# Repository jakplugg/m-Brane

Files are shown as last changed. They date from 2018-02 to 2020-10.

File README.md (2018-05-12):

# m-Brane
6hp eurorack module, compact verion of Mutable Instruments Yarns.

Google sheet BOM:
https://docs.google.com/spreadsheets/d/1MqaRt3kgtec8WGIdC7prpy5DM8mcHv3j_mBwdBO56kk/edit?usp=sharing

CC-BY-SA-3.0 (todo:add license file)

re the MIDI jacks, you can use kobiconn stereo jacks (pc mount, not solder tab) instead of the thonk ones, but you should pull them up to the panel with the nut before soldering them, because they are a little shorter than the thonk ones.

Note: Early versions of the board have the gate outs reversed, (but not the LEDs) there is an alternative firmware in the "reverse_gates_firmware" folder

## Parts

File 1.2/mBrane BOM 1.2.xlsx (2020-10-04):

 | RefDes | Value | Name | Mouser | Notes
4 | C14, C16, C21, C22 | 18p | C-USC0603 | 81-GRM185C1H180JA01J
13 | C2, C5, C6, C8, C9, C11, C13, C18, C19, C20, C23, C24, C27 | 100n | C-USC0603 | 963-EMK107BJ104KAHT
1 | C17 | 220n | C-USC0603 | 81-GRM188R71C224KA1J
2 | C25, C26 | 1u | C-USC0603 | 81-GRM188R61E105KA2J
1 | C15 | 3.3u | C-USC0603 | 81-GRM188R61A335KE5D
2 | C3, C12 | 10u | CPOL-USA | 647-UWP1A100MCL
2 | C1, C4 | 22u | CPOL-USC | 667-EEE-FK1E220R
2 | R39, R40 | 51 | R-US_R0603 | 603-RC0603FR-0751RL (https://www.mouser.com/ProductDetail/Yageo/RC0603FR-0751RL?qs=sGAEpiMZZMu61qfTUdNhG5eFuApKbqVdiaQZYTuEmh8%3d)
18 | R2, R3, R4, R5, R6, R7, R8, R10, R11, R12, R13, R14, R15, R16, R33, R36, R41, R42 | 100 | R-US_R0603 | 603-RC0603FR-07100RL
1 | R75 | 220 | R-US_R0603 | 603-RC0603FR-07220RL
10 | R1, R9, R24, R25, R30, R31, R32, R34, R38, R43 | 1.0k | R-US_R0603 | RC0603FR-071KL
2 | R17, R37 | 10k | R-US_R0603 | 603-RC0603FR-0710KL
6 | R18, R19, R20, R21, R22, R23 | 47k | R-US_R0603 | 603-RC0603FR-0747KL
4 | R26, R27, R28, R29 | 240k | R-US_R0603 | RC0603FR-07240KL
1 | D20 | MB1S | MB1S | 512-MB1S
1 | D1, D2 | BAT54S | DIODE
1 | IC1 | LM1117-3.3 | REG1117 | 926-LM1117MPX3.3NOPB
2 | IC2, IC3 | 74HC595D | 74HC595D | 595-CD74HC595M
1 | IC4 | DAC8564 | DAC8564 | 595-DAC8564IDPW
1 | IC5 | REF02D | REF02D | 595-REF02AU
1 | IC6 | OPA4171 | TL074D | 595-OPA4171AIDR
4 | IC7, IC8, IC10, IC11 | 74AHCT1G125DBV | 74AHCT1G125DBV | 595-SNAHCT1G125DBVR
1 | IC9 | MCP1703CB | MCP1703CB | 579-MCP1703T-5002ECB
1 | UC1 | STM32F103CBT6 | STM32F103CB | 511-STM32F103CBT6
1 | U10 | 8 mhz resonator | smd-crystal | CSTCE8M00GH5C99-R0
2 | Q1, Q2 | MMBT3904 | MMBT3904LT1-NPN-SOT23-BEC | 863-MMBT3904LT1G
1 | OK1 | 6N137SMT | 6N137SMT | 512-HCPL0600
26 | Unique
86 | Total

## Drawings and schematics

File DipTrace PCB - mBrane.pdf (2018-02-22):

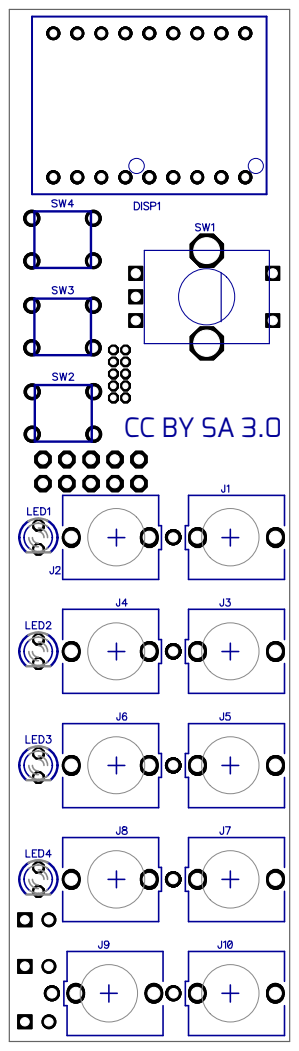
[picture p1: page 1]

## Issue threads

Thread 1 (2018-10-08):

Midi In doesn't work

gboxentertainment, 2018-10-08:
I built a Midi (male) to 3.5mm TRS adapter, but have not been able to get it to work with the m-Brane. I have tested this cable on other hardware and it sends midi fine.

I switch Tempo to Ext and Channel to All.

I have tried switching pins 4 and 5 on the midi pinout connections but it doesn't make a difference. I have found that connecting Tip to pin 5 and Ring to pin 4 makes the midi cable work as a trigger directly into any trigger inputs on any of my modules. But no matter which way I switch it, I still can't get Midi working on the m-Brane. I have Sleeve connected to pin 2 on the midi socket.

I suspect that it may be the HCPL0600, which you have on your BOM to replace the 6N137 from the original Yarns. It has slightly different specs but the internal circuits are the same.

Closed 2020-09-15.

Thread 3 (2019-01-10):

possible to post sysex for reversed gates firmware?

seanrieger, 2019-01-10:
So I am one of the users with the early board version that has reversed gates, but not reversed LED's  Could you please post the sysex file for that firmware as well, as I don't have a programmer, and no longer am in touch with the person who flashed my chip.

Closed 2020-09-15.

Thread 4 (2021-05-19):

Jumpers

pjbulls, 2021-05-19:
Hiya,

how exactly do the jumpers work, particularly in v1.2? I can kind of guess that J13 and J14 support TRS MIDI A and B, but I have no idea what J11 and J12 are for...

jakplugg, 2021-05-19:
J11 is in parallel with MIDI in and j12 is in parallel with MIDI out, in
case someone wanted to wire a 5 pin MIDI jack to the back of their case or
something like that.

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

pjbulls, 2021-05-19:
Alright, thanks, that makes sense. I was trying to wrap my head around why you'd want to short those connections together, didn't think of just tapping them from these points.

Closed 2021-05-19.

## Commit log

2018-02-03 added files
    added initial files to be getting on with
    [working.GBL, working.GBO, working.GBP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]
2018-02-22 board pic for panel align
2018-06-10 synced board and gerbers
    old board diptrace file was still up
    [mBrane.GBL, mBrane.GBO, mBrane.GBP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]
2020-10-04 1.2 added
    added 1.2 version with "either way" MIDI in and jumper for MIDI out
    polarity
    [mBrane_02.DRL, mBrane_02.GBL, mBrane_02.GBO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]
2020-10-04 added bom and pno files
    [mBrane BOM 1.2.xlsx, mBrane1.2_PNP_JLC.csv]
